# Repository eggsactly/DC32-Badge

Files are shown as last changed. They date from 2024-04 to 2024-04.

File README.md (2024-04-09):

# About 
The DEFCON 32 CPEC badge design, done in kicad 6. Repo contains both a schematic and PCB design. 

This design uses the pervasive displays E2266QS0F1 E-Ink display; https://www.pervasivedisplays.com/product/2-66-e-ink-displays/

## Goal (functional requirements)
Design of the final board will do these functions. Many of them will be implemented in embedded software, which the board hardware will enable. 

- When the user attaches a lanyard to the two holes cut into the top of the board, the user will be able to wear this board around their neck. 
- When the user turns on the board, the board will read the contents of the SD card, and will display the first BMP file on the e-ink display.
- When the user pushes the image select button, SW4, the board will display the next BMP on the SD card.
- When the user plugs in an SAO board to J3, J4, or J5, the board will supply 3.3v DC power to the SAO board. 
- Board will be programmed over UART with a FTDI cable. When the developer switches SW5 to program, plugs a FTDI cable into J1, and presses SW3 to reset the board, the developer will load their ESP32 image over the serial bus. 
- When the user switches switch SW2 to "Be Evil" the board will do something mischievous. 
- LEDs will blink in a cool pattern. 

# Questions/Risks  (non-functional requirements)
This section covers specific questions and possible risks, which may lead to non-functional requirements on the design. 

## Specific Questions
- Can the ESP32-S2-WROOM-1 "EN" in be used as a Chip Pullup?
- Can the ESP32-S2-WROOM-1 "GPIO2" be used as a SPI Data Out pin?
- Can the ESP32-S2-WROOM-1 "GPIO3" be used as a SPI Chip Select pin? 
- Can the ESP32-S2-WROOM-1 "GPIO6" be used as a SPI Clock pin? 
- Can the ESP32-S2-WROOM-1 "GPIO7" be used as a SPI Data In pin? 

## Risks
- The SPI clock line is longer than the data line on the PCB layout. This may lead to a drift in the SPI clock from the data. May lead to an inability to use the Display or SD card. 
- Something about this design may be non-manufacturable 
  - Are vias too close to lines? 
  - Are there too many vias? 
  - Are some lines too close to the edge? 
  - Are some lines too close together? 
  - Are some pads too small? 

# Details 

Kicad version
```
Application: KiCad

Version: 6.0.11+dfsg-1, release build

Libraries:
	wxWidgets 3.2.2
	libcurl/7.88.1 OpenSSL/3.0.11 zlib/1.2.13 brotli/1.0.9 zstd/1.5.4 libidn2/2.3.3 libpsl/0.21.2 (+libidn2/2.3.3) libssh2/1.10.0 nghttp2/1.52.0 librtmp/2.3 OpenLDAP/2.5.13

Platform: Linux 6.1.0-18-amd64 x86_64, 64 bit, Little endian, wxGTK, gnome, wayland

Build Info:
	Date: Jan 26 2023 05:35:43
	wxWidgets: 3.2.1 (wchar_t,wx containers) GTK+ 3.24
	Boost: 1.74.0
	OCC: 7.6.3
	Curl: 7.87.0
	ngspice: 38
	Compiler: GCC 12.2.0 with C++ ABI 1017

Build settings:
	KICAD_USE_OCC=ON
	KICAD_SPICE=ON
```

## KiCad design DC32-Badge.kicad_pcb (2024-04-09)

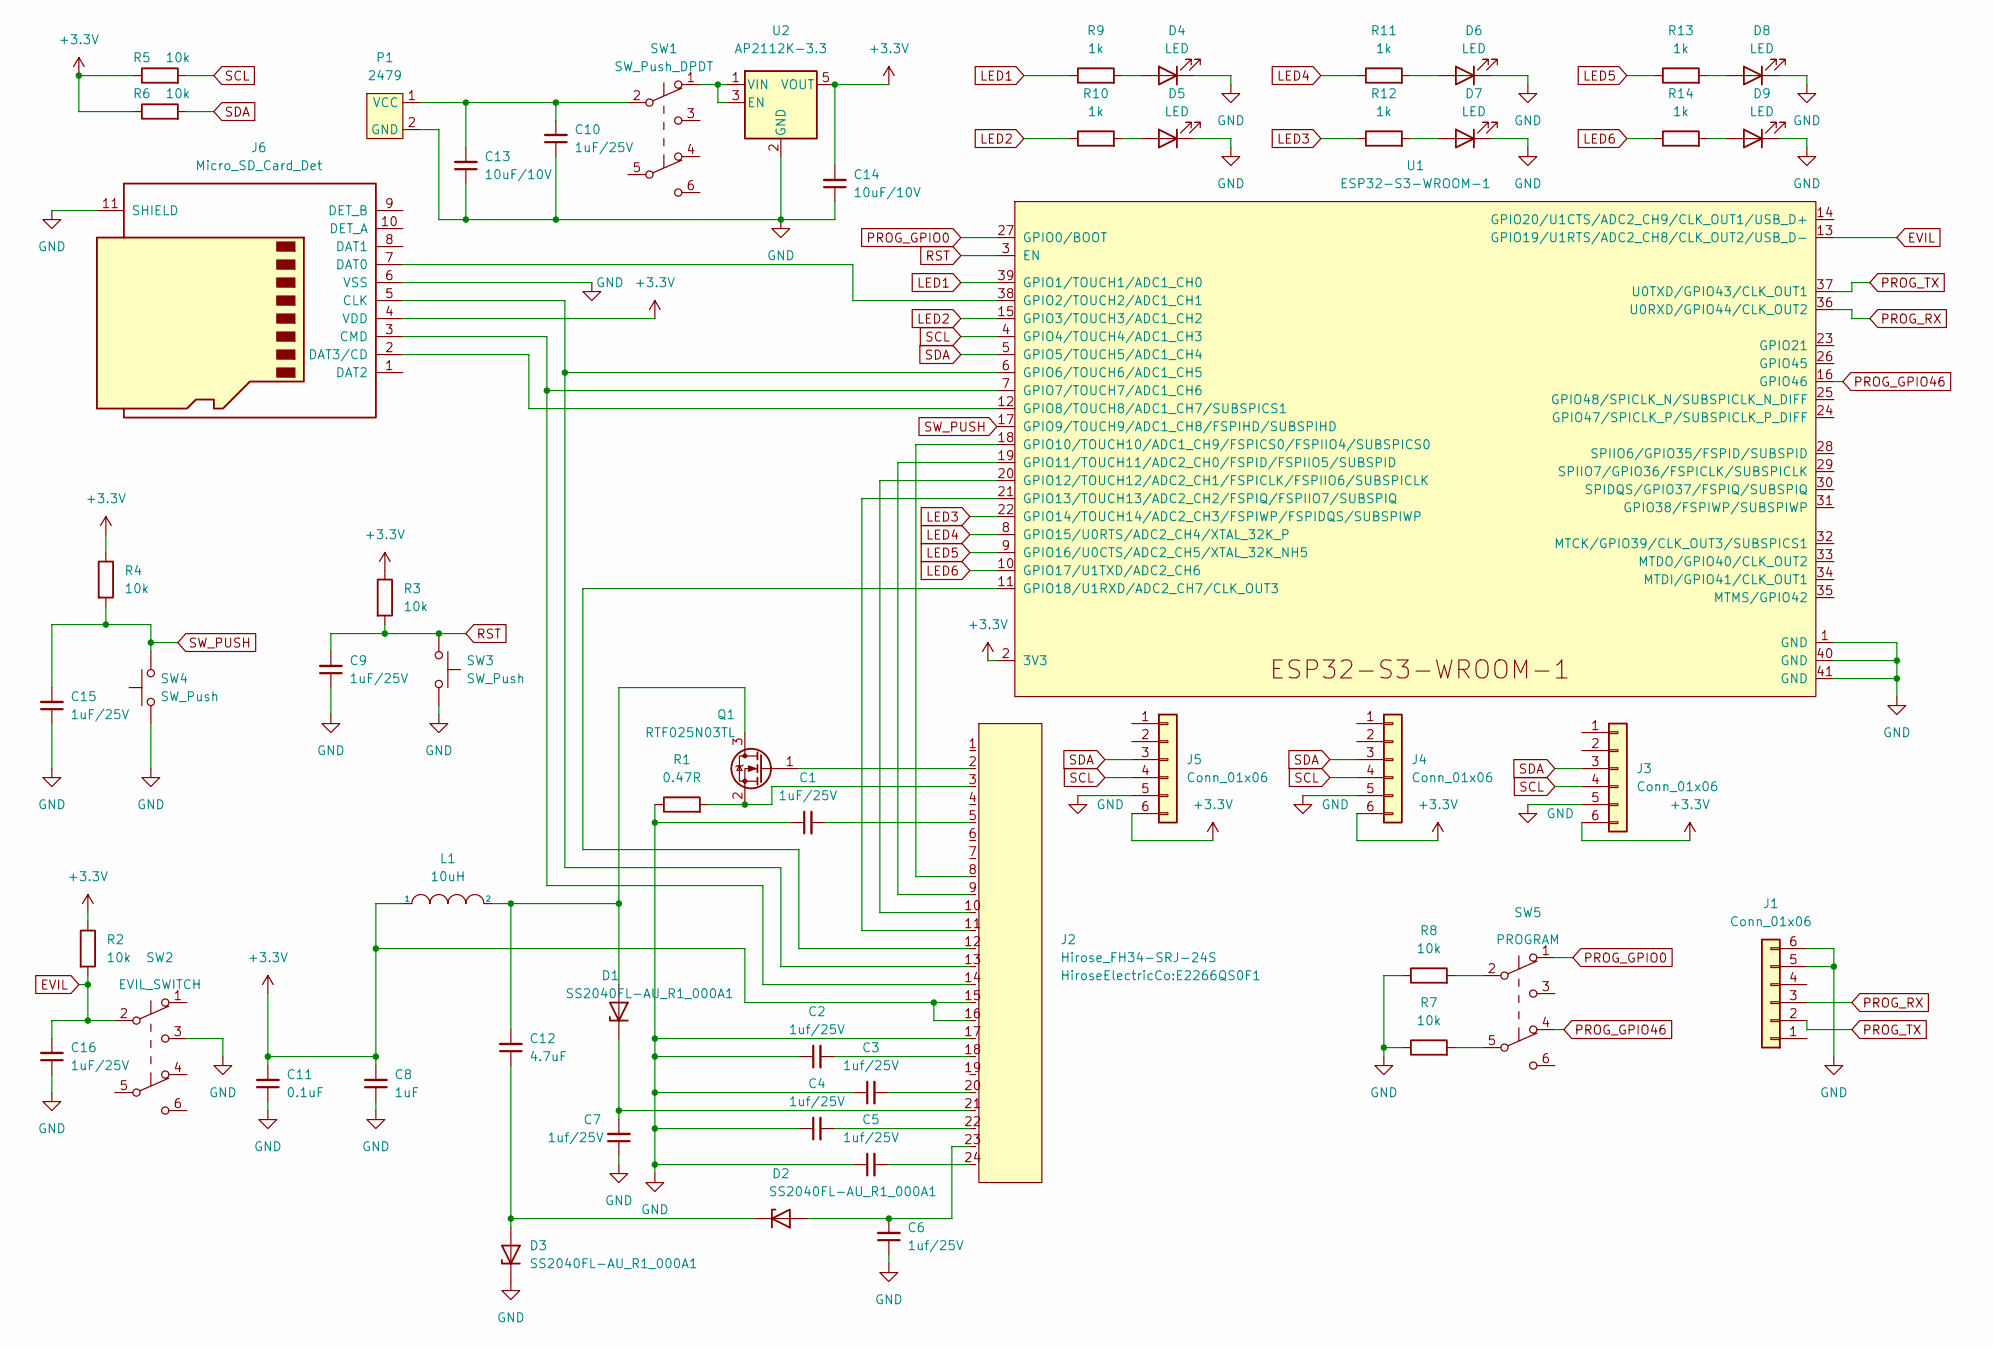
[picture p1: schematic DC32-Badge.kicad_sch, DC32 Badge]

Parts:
C1, C9, C10, C15, C16: 1uF/25V; C_0603_1608Metric
C2, C3, C4, C5, C6, C7: 1uf/25V; C_0603_1608Metric
C8: 1uF; C_0603_1608Metric
C11: 0.1uF; C_0402_1005Metric
C12: 4.7uF; C_0805_2012Metric
C13, C14: 10uF/10V; C_0805_2012Metric
D1, D2, D3: SS2040FL-AU_R1_000A1; D_SOD-123F
D4, D5, D6, D7, D8, D9: LED; LED_0201_0603Metric
J1: Conn_01x06; PinSocket_1x06_P2.54mm_Vertical_SMD_Pin1Left
J2: Hirose_FH34-SRJ-24S; E2266QS0F1
J3, J4, J5: Conn_01x06; PinHeader_2x03_P2.54mm_Vertical
J6: Micro_SD_Card_Det; microSD_HC_Hirose_DM3AT-SF-PEJM5
L1: 10uH; L_0805_2012Metric
P1: 2479; BatteryHolder_Keystone_2479_3xAAA
Q1: RTF025N03TL; SOT-323_SC-70
R1: 0.47R; R_0603_1608Metric
R2, R3, R4, R5, R6, R7, R8: 10k; R_0603_1608Metric
R9, R10, R11, R12, R13, R14: 1k; R_0603_1608Metric
SW1: SW_Push_DPDT; SW_E-Switch_EG1271_SPDT
SW2: EVIL_SWITCH; SW_E-Switch_EG1271_SPDT
SW3, SW4: SW_Push; SW_SPST_B3S-1000
SW5: PROGRAM; SW_E-Switch_EG1271_SPDT
U1: ESP32-S3-WROOM-1
U2: AP2112K-3.3; SOT-23-5

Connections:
+3.3V: C8.2, C11.2, C14.2, J2.15, J2.16, J3.6, J4.6, J5.6, J6.4 (VDD), L1.1, R2.1, R3.1, R4.1, R5.1, R6.1, U1.2 (3V3), U2.5 (VOUT)
EVIL: C16.2, R2.2, SW2.2 (B), U1.13 (GPIO19/U1RTS/ADC2_CH8/CLK_OUT2/USB_D-)
GND: C1.1, C2.1, C3.1, C4.1, C5.1, C6.1, C7.1, C8.1, C9.1, C10.1, C11.1, C13.1, C14.1, C15.1, C16.1, D3.1 (K), D4.1 (K), D5.1 (K), D6.1 (K), D7.1 (K), D8.1 (K), D9.1 (K), J1.5, J1.6, J2.17, J3.5, J4.5, J5.5, J6.6 (VSS), J6.11 (SHIELD), P1.2 (GND), R1.1, R7.1, R8.1, SW2.3 (C), SW3.2, SW4.1, U1.1 (GND), U1.40 (GND), U1.41 (GND), U2.2 (GND)
LED1: R9.1, U1.39 (GPIO1/TOUCH1/ADC1_CH0)
LED2: R10.1, U1.15 (GPIO3/TOUCH3/ADC1_CH2)
LED3: R12.1, U1.22 (GPIO14/TOUCH14/ADC2_CH3/FSPIWP/FSPIDQS/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)
LED4: R11.1, U1.8 (GPIO15/U0RTS/ADC2_CH4/XTAL_32K_P)
LED5: R13.1, U1.9 (GPIO16/U0CTS/ADC2_CH5/XTAL_32K_NH5)
LED6: R14.1, U1.10 (GPIO17/U1TXD/ADC2_CH6)
unnamed: C1.2, J2.5
unnamed: C2.2, J2.18
unnamed: C3.2, J2.20
unnamed: C4.2, J2.22
unnamed: C5.2, J2.24
unnamed: C6.2, D2.2 (A), J2.23
unnamed: C7.2, D1.1 (K), J2.21
unnamed: C10.2, C13.2, P1.1 (VCC), SW1.2 (B)
unnamed: C12.1, D2.1 (K), D3.2 (A)
unnamed: C12.2, D1.2 (A), L1.2, Q1.3 (D)
unnamed: D4.2 (A), R9.2
unnamed: D5.2 (A), R10.2
unnamed: D6.2 (A), R11.2
unnamed: D7.2 (A), R12.2
unnamed: D8.2 (A), R13.2
unnamed: D9.2 (A), R14.2
unnamed: J2.2, Q1.1 (G)
unnamed: J2.3, Q1.2 (S), R1.2
unnamed: J2.8, U1.18 (GPIO10/TOUCH10/ADC1_CH9/FSPICS0/FSPIIO4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)
unnamed: J2.9, U1.19 (GPIO11/TOUCH11/ADC2_CH0/FSPID/FSPIIO5/S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)
unnamed: J2.10, U1.20 (GPIO12/TOUCH12/ADC2_CH1/FSPICLK/FSPIIO6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)
unnamed: J2.11, U1.21 (GPIO13/TOUCH13/ADC2_CH2/FSPIQ/FSPIIO7/S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)
unnamed: J2.12, U1.11 (GPIO18/U1RXD/ADC2_CH7/CLK_OUT3)
unnamed: J2.13, J6.5 (CLK), U1.6 (GPIO6/TOUCH6/ADC1_CH5)
unnamed: J2.14, J6.3 (CMD), U1.7 (GPIO7/TOUCH7/ADC1_CH6)
unnamed: J6.2 (DAT3/CD), U1.12 (GPIO8/TOUCH8/ADC1_CH7/SUBSPICS1)
unnamed: J6.7 (DAT0), U1.38 (GPIO2/TOUCH2/ADC1_CH1)
unnamed: R7.2, SW5.5 (B)
unnamed: R8.2, SW5.2 (B)
unnamed: SW1.1 (A), U2.1 (VIN), U2.3 (EN)
PROG_GPIO0: SW5.1 (A), U1.27 (GPIO0/BOOT)
PROG_GPIO46: SW5.4 (A), U1.16 (GPIO46)
PROG_RX: J1.3, U1.36 (U0RXD/GPIO44/CLK_OUT2)
PROG_TX: J1.2, U1.37 (U0TXD/GPIO43/CLK_OUT1)
RST: C9.2, R3.2, SW3.1, U1.3 (EN)
SCL: J3.4, J4.4, J5.4, R5.2, U1.4 (GPIO4/TOUCH4/ADC1_CH3)
SDA: J3.3, J4.3, J5.3, R6.2, U1.5 (GPIO5/TOUCH5/ADC1_CH4)
SW_PUSH: C15.2, R4.2, SW4.2, U1.17 (GPIO9/TOUCH9/ADC1_CH8/FSPIHD/SUBSPIHD)

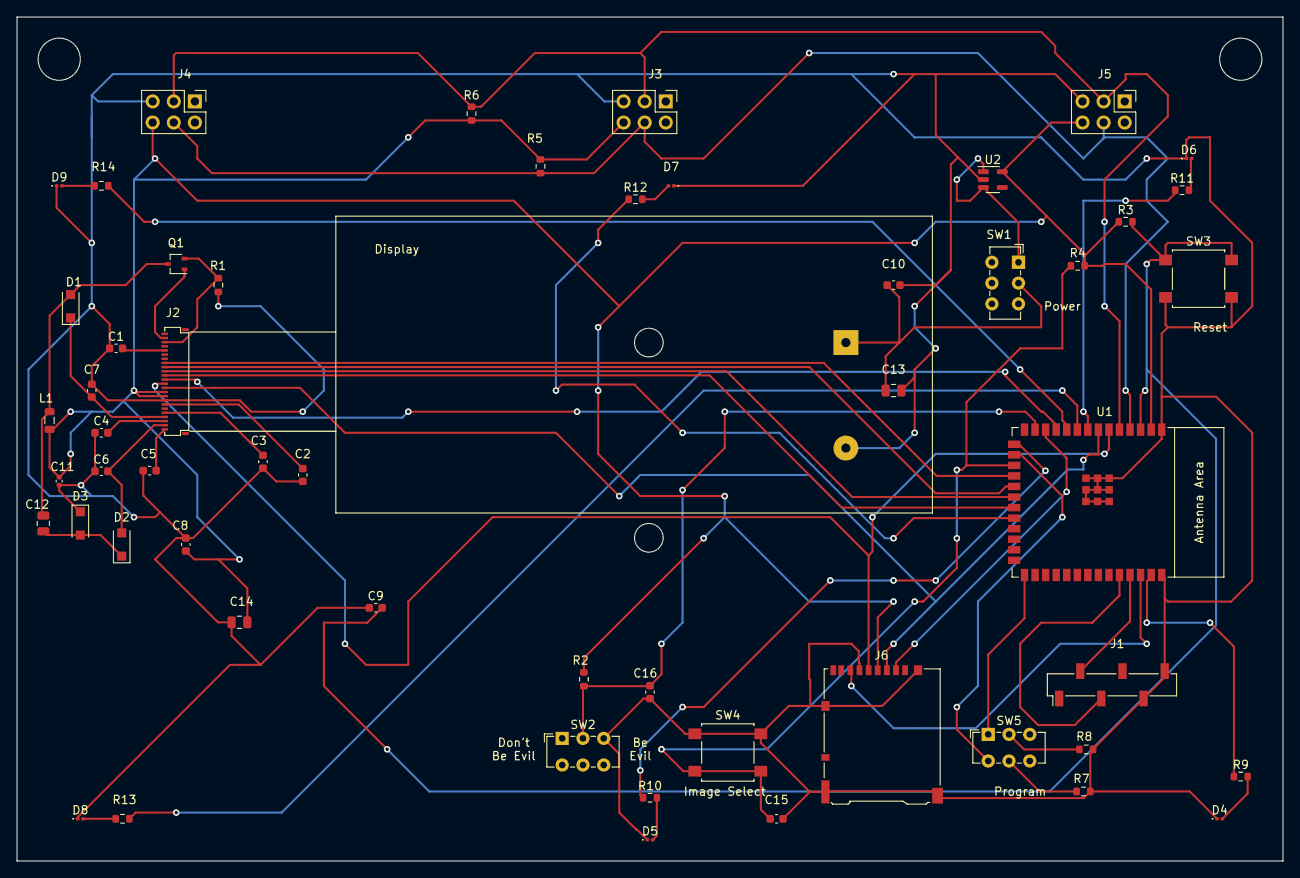
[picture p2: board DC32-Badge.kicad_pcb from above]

Board: 2 copper layers, 152.4 x 101.6 mm, 55 parts (1 on the bottom side), 47 nets.

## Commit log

2024-04-01 Initial commit.
    [DC32-Badge.kicad_pcb, DC32-Badge.kicad_sch]
2024-04-01 Replaced ESP32-MINI with ESP32-WROOM in the kicad_sch file.
    [DC32-Badge.kicad_sch]
2024-04-02 Fit design on one page by modularizon. Added some button debouncing capacitors. Changed some of the GPIO pins.
    [DC32-Badge.kicad_sch]
2024-04-02 Added third SAO port.
    [DC32-Badge.kicad_sch]
2024-04-02 Rearranged some pins. Added a PROGRAM switch.
    [DC32-Badge.kicad_sch]
2024-04-02 Ran electrical rules checker.
    [DC32-Badge.kicad_sch]
2024-04-02 Added 6 LEDs
    [DC32-Badge.kicad_sch]
2024-04-02 Initial place and route.
    [DC32-Badge.kicad_pcb]
2024-04-02 Adjustments prior to route.
    [DC32-Badge.kicad_pcb]
2024-04-02 Changed SAO board footprint to a throughhole footprint.
    [DC32-Badge.kicad_pcb, DC32-Badge.kicad_sch]
2024-04-02 Updated footprint library in schematic editor. Rearranged some componets on the PCB editor.
    [DC32-Badge.kicad_pcb, DC32-Badge.kicad_sch]
2024-04-05 Initial route.
    [DC32-Badge.kicad_pcb]
2024-04-07 Updated placing and routing for power capacitors.
    [DC32-Badge.kicad_pcb]
2024-04-09 Updated silkscreen.
    [DC32-Badge.kicad_pcb]
